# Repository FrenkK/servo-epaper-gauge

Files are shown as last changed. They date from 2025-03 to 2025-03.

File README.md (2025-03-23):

# Triple Analog Gauge Using Servos and an E-paper Display
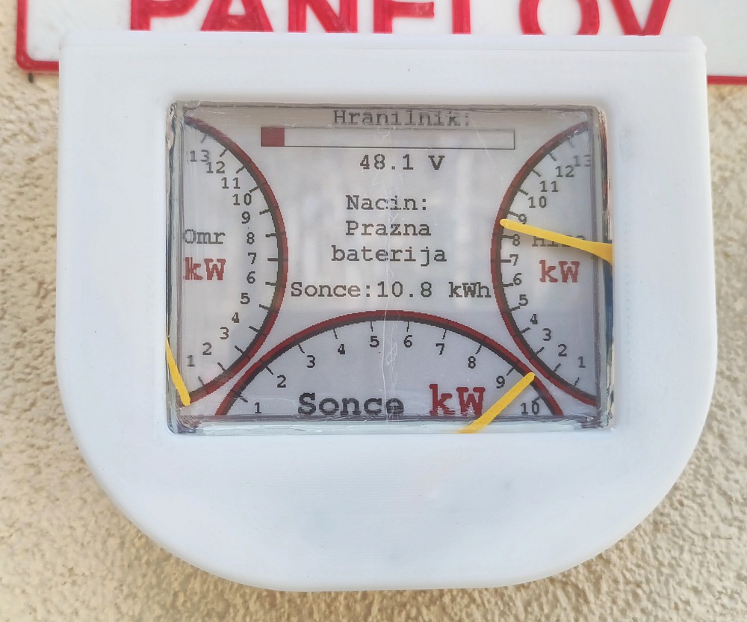
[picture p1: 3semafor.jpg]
The gauge

A simple triple gauge using three servos and a 3-color e-paper display used for indicating a solar system state.
The project uses 3 90g servos to move needles and an e-paper display to display both gauge markings and extra information about the system state.
Inspired by [Arne van Iterson](https://arnweb.nl/gitea/arne/EinkAnalog).

# What you need
- An ESPP32 dev board
- Waveshare 4.2" 3-color e-paper display (there are two versions, one with screw holes in the back and one with screw holes next to the display, you need the first one or the mounting biard will not fit)
- 3 90g servos
- Some screws from your screw drawer ;)
- A 3D-printer
- Weatherproof filament like ASA or ABS
- Some acryllic to make the window

# STEP files
The project includes STEP files for 3d-printing an enclosure:
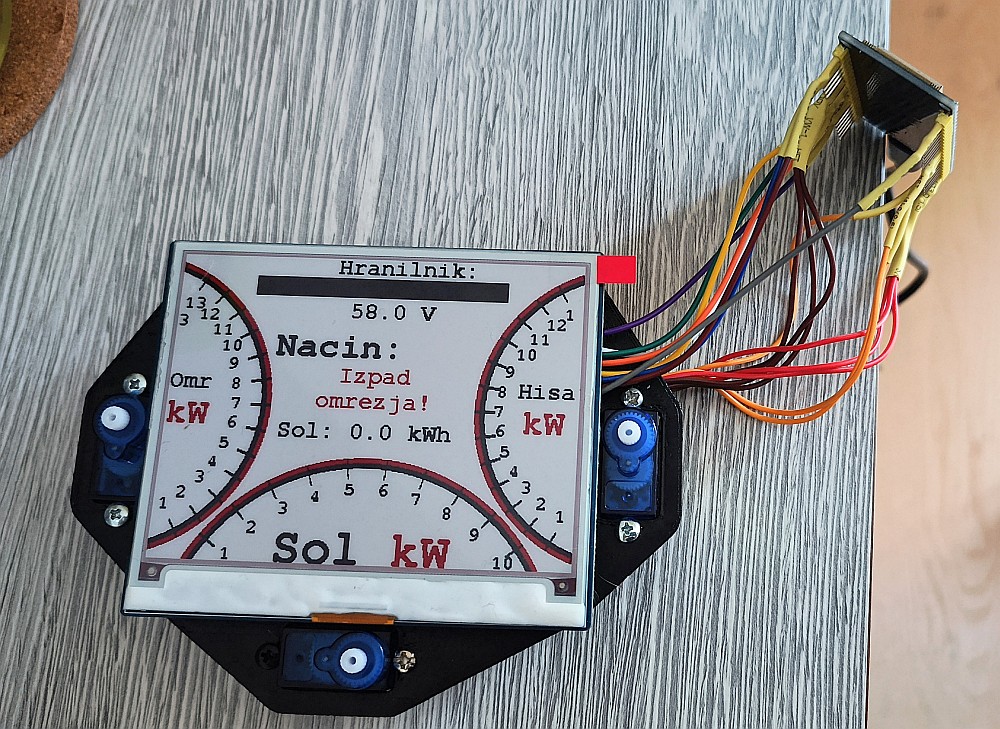
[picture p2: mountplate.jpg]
The mounting plate
- Ogrodje za tri.step is the mounting plate for the servos and the e-paper display (Waveshare 3-color 4.2") mounting plate. 
- Ohišje za semafor lope.step is the housing with a cover. Print this in something that will take direct sunlight, like ABS or ASA. You have to drill a hole for the power cable in an appropriate spot. If exposed to elements, glue an acryllic plate on the inside using silicone to make it watertight. Finally, slide the mounting plate in the grooves inside and use a drop of superglue to mount the cover.
- Kazalec za lopo.step contains two versions of needles for the servos, short one is for the two side servos and the long one for the center one.

# Arduino code
This is the code for the ESP32 controller driving the display and servos. The header files are for the GxEPD2 library and contain display definition and pin connections.

# Connections
- E-paper display should be connected to 3.3V and GND power rails of the ESP32 and the pins listed in the 'GxEPD2_wiring_examples.h' header file for the exact ESP32 board you are using.
- Connect the servos power lines to the 5V and GND power rails of the ESP32 board, and then connect the control lines to the pins set in the Arduino code (25, 26, and 27 in my case).
- Finally, connect the ESP32 board to an USB power cable or directly solder a 1A, 5V voltage supply to the 5V and GND power rails of the ESP32 board.

# TBD
- OTA firmware upload
- Better Wi-fi disturbances handling
- Less lame programming skills

Happy DIY :)
Franci

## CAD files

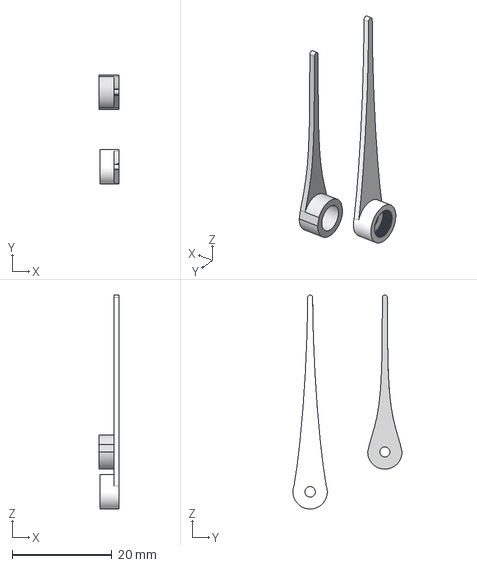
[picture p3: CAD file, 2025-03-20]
Kazalec za lopo.step
4.00 x 21.9 x 43.0 mm

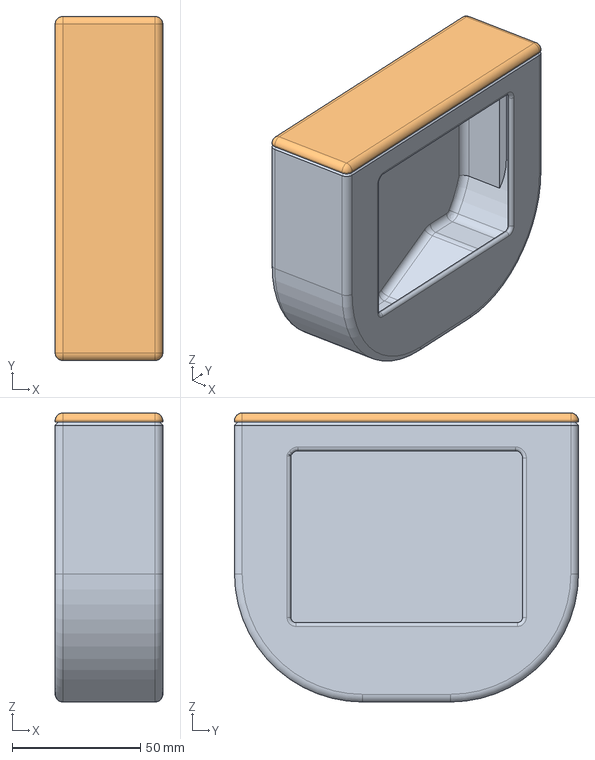
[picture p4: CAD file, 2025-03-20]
Ohišje za semafor lope.step
42.0 x 134.2 x 112.7 mm

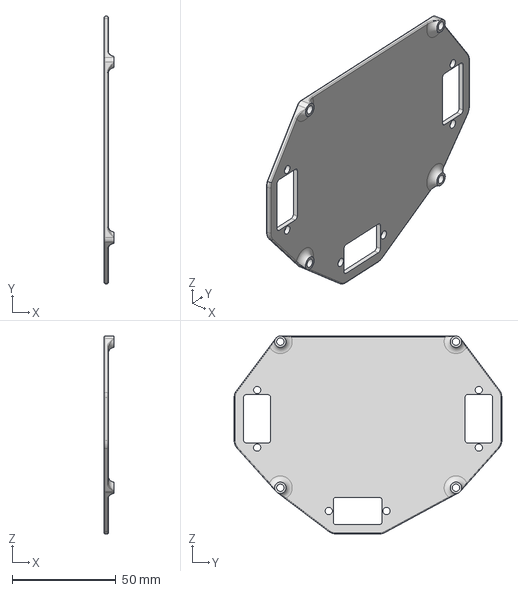
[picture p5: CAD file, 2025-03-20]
Ogrodje za tri.step
4.68 x 129.2 x 95.6 mm

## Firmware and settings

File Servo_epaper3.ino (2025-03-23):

#define ENABLE_GxEPD2_GFX 0

#include <GxEPD2_BW.h> // Include library for monochrome e-paper display
#include <GxEPD2_3C.h> // Include library for tri-color e-paper display
#include <Fonts/FreeMonoBold18pt7b.h> // Include font library for bold text at 18pt
#include <Fonts/FreeMonoBold9pt7b.h> // Include font library for bold text at 9pt
#include <Fonts/FreeMonoBold24pt7b.h> // Include font library for bold text at 24pt
#include <Fonts/FreeMonoBold12pt7b.h> // Include font library for bold text at 12pt
#include <Fonts/FreeMono12pt7b.h> // Include font library for standard text at 12pt
#include "GxEPD2_display_selection_new_style.h" // Include custom display selection header file
#include <ESP32Servo.h> // Include servo library for motor control
#include <WiFi.h> // Include WiFi library for network communication
#include "Adafruit_MQTT.h" // Include MQTT library for messaging
#include "Adafruit_MQTT_Client.h" // Include MQTT client library

// Define WiFi access parameters
// Code credit: https://randomnerdtutorials.com/esp32-useful-wi-fi-functions-arduino/#3
const char *SSID = "ssid"; // Network name (SSID)
const char *wifiPass = "pass"; // Password for network connection
const char *hostName = "prikaz-lopa"; // Hostname for MQTT communication
WiFiClient wifiClient; // Create WiFi client object

// Define MQTT broker parameters
// Code credit: https://www.donskytech.com/adafruit-mqtt-library-tutorial/
const char *mqttBroker = "broker"; // Name of MQTT broker
const int mqttPort = 1883; // Port number for MQTT communication
const char *mqttUserName = "user"; // Username for MQTT connection
const char *mqttUserPassword = "pass"; // Password for MQTT connection

// Create Adafruit MQTT client object with WiFi client as underlying transport layer
Adafruit_MQTT_Client mqtt(&wifiClient, mqttBroker, mqttPort, mqttUserName, mqttUserPassword);

// Define MQTT subscription topics
const char *subscribeGridTopic = "power/grid"; // Topic for grid power data
const char *subscribeSolarTopic = "power/solar"; // Topic for solar production power data
const char *subscribeHouseTopic = "power/house"; // Topic for house power consumption data
const char *subscribeModeTopic = "power/mode"; // Topic for mode of operation (normal or emergency)
const char *subscribeBatteryTopic = "power/battery"; // Topic for battery voltage and state
const char *subscribeEnergyTopic = "power/energy"; // Topic for total energy produced/consumed

// Create MQTT subscriber objects for each topic
Adafruit_MQTT_Subscribe gridPowerRef = Adafruit_MQTT_Subscribe(&mqtt, subscribeGridTopic, MQTT_QOS_0); // Subscribe to grid power data at QoS 1
Adafruit_MQTT_Subscribe solarPowerRef = Adafruit_MQTT_Subscribe(&mqtt, subscribeSolarTopic, MQTT_QOS_0); // Subscribe to solar panel power data at QoS 1
Adafruit_MQTT_Subscribe housePowerRef = Adafruit_MQTT_Subscribe(&mqtt, subscribeHouseTopic, MQTT_QOS_0); // Subscribe to house power consumption data at QoS 1
Adafruit_MQTT_Subscribe modeRef = Adafruit_MQTT_Subscribe(&mqtt, subscribeModeTopic, MQTT_QOS_0); // Subscribe to mode of operation (normal or emergency) at QoS 1
Adafruit_MQTT_Subscribe batteryRef = Adafruit_MQTT_Subscribe(&mqtt, subscribeBatteryTopic, MQTT_QOS_0); // Subscribe to battery voltage and state data at QoS 1
Adafruit_MQTT_Subscribe energyRef = Adafruit_MQTT_Subscribe(&mqtt, subscribeEnergyTopic, MQTT_QOS_0); // Subscribe to total energy produced/consumed data at QoS 1

//Servo defs
//Left servo init
Servo leftServo;  // create servo object to control a servo
int leftServoStart = 20; // servo value for 0
int leftServoEnd = 177; // servo value for maxPower
int leftServoPin = 25; // Pin number for connecting left servo
//Servo 2 init
Servo centerServo;  // create servo object to control a servo
int centerServoStart = 177; // servo value for 0
int centerServoEnd = 31; // servo value for maxPower
int centerServoPin = 26; // pin number for connecting center servo
//Servo 3 init
Servo rightServo;  // create servo object to control a servo
int rightServoStart = 177; // servo value for 0
int rightServoEnd = 20; // servo value for maxPower
int rightServoPin = 27; // pin number for connecting right servo

//Globals
String mode1 = ""; // First line of status display
String mode2 = ""; // Second line of status display
float batteryVoltage = 58; // Battery voltage
float producedEnergy = 0; // Total energy produced today
long lastRefresh = 0; // Timestamp of last screen refresh
bool normalMode = false; // Normal mode flag

//Constants

// Status strings
// The following constants are used to display the current mode on the screen.
// These string values represent different modes of operation and their corresponding status messages.

// In emergency charging mode (deep discharge prevention), show the following messages on the first and second lines.
const String emergencyString1 = "Zasilno";
const String emergencyString2 = "polnjenje";
// If the battery is empty, show these strings on the first and second lines.
const String batEmptyString1 = "Prazna";
const String batEmptyString2 = "baterija";
// When in normal mode, display these strings on the first and second lines.
const String normalString1 = "Na";
const String normalString2 = "bateriji";
// If the battery is full, display these strings on the first and second lines.
const String fullString1 = "Polna";
const String fullString2 = "baterija";
// When there's no grid power available, display these strings on the first and second lines.
const String noGridString1 = "Izpad";
const String noGridString2 = "omrezja!";

// Number constants
// Maximum house power consumption
const float maxHousePower = 14000; // Watts (W)
// Maximum grid power consumption
const float maxGridPower = 14000; // W
// Maximum solar panel power generation
const float maxSolarPower = 11000; // W
// Maximum battery voltage
const float maxVoltage = 58; // Volts (V)
// Minimum battery voltage
const float minVoltage = 47; // V
// Low battery threshold, used to change display color to red when lower than this value
const float lowVoltage = 49; // V
// Minimum and maximum angles for left servo motor in radians
const float alphaMinLeft = 20 * DEG_TO_RAD; // rad
const float alphaMaxLeft = 160 * DEG_TO_RAD; // rad
// Minimum and maximum angles for center servo motor in radians
const float alphaMinCenter = 25 * DEG_TO_RAD; // rad
const float alphaMaxCenter = 155 * DEG_TO_RAD; // rad
// Minimum and maximum angles for right servo motor in radians
const float alphaMinRight = 20 * DEG_TO_RAD; // rad
const float alphaMaxRight = 160 * DEG_TO_RAD; // rad
// Coordinates of center points for left, center, and right servos on the screen
const int xCLeft = -49; // x-coordinate (pixels)
const int yCLeft = 150; // y-coordinate (pixels)
const int RLeft = 150; // radius (pixels)
const int xCCenter = 200; // x-coordinate (pixels)
const int yCCenter = 389; // y-coordinate (pixels)
const int RCenter = 190; // radius (pixels)
const int xCRight = 449; // x-coordinate (pixels)
const int yCRight = 150; // y-coordinate (pixels)
const int RRight = 150; // radius (pixels)
// Refresh time for display in milliseconds
const long refreshTime = 600000; // ms

/**
 * Initialize WiFi connection.
 *
 * Connects to the specified network with the given credentials and sets up WiFi configuration.
 */
void initWiFi() {
  // Set host name of ESP32 device
  WiFi.setHostname(hostName);

  // Set WiFi mode to station (STA) mode, which means we're a client, not an access point
  WiFi.mode(WIFI_STA);

  // Start WiFi connection with given credentials
  WiFi.begin(SSID, wifiPass);

  // Print dots while waiting for WiFi connection
  Serial.print("Connecting to WiFi ..");
  while (WiFi.status() != WL_CONNECTED) {
    Serial.print('.');
    delay(1000); // wait 1 second between dots
  }

  // Print successful connection message and display local IP address
  Serial.println(WiFi.localIP());
}

// Function to connect and reconnect as necessary to the MQTT server.
// Should be called in the loop function and it will take care if connecting.
void connectToMQTTServer() {
  // Print a comment indicating that this function is being called
  Serial.println("Connecting to MQTT...");

  int8_t ret = mqtt.connect(); // Attempt connection to MQTT server

  while (ret != 0) { // Check if connection was successful
    // If connection failed, print an error message and wait for 10 seconds before retrying
    Serial.print("Failed to connect: ");
    Serial.println(mqtt.connectErrorString(ret));
    Serial.println("Retrying MQTT connection in 10 seconds...");
    delay(10000); // Wait for 10 seconds

    ret = mqtt.connect(); // Attempt connection again
  }

  // Print a comment indicating that the connection was successful
  Serial.println("MQTT Connected!");
}

// Function to draw the battery gauge on the e-paper display.
// The battery gauge is a rectangle with a filled part that represents the battery voltage.
// The filled part is colored black if the battery voltage is above the low voltage threshold, and red otherwise.
// The battery voltage is displayed in volts at the bottom of the gauge.
// The function takes the battery voltage as input and draws the gauge accordingly.
void drawBatteryGauge(float batteryVoltage)
{
  int gaugeWidth = 250; // Width of the battery gauge
  int gaugeHeight = 20; // Height of the battery gauge
  int gaugeX = 75; // X position of the battery gauge
  int gaugeY = 20; // Y position of the battery gauge

  // Draw the outline of the battery
  display.drawRect(gaugeX, gaugeY, gaugeWidth, gaugeHeight, GxEPD_BLACK);

  // Limit values for bar
  float tempBatteryVoltage=0;
  if ((batteryVoltage>minVoltage)&&(batteryVoltage<maxVoltage)) { // If battery voltage is within limits, use it
    tempBatteryVoltage=batteryVoltage;
  } else if (batteryVoltage<=minVoltage) { // If battery voltage is below minimum limit, use minimum
    tempBatteryVoltage=minVoltage;
  } else if (batteryVoltage>=maxVoltage) { // If battery voltage is above maximum limit, use maximum
    tempBatteryVoltage=maxVoltage;
  }

  // Calculate the width of the filled part based on battery voltage
  int filledWidth = ((tempBatteryVoltage-minVoltage)/(maxVoltage-minVoltage)) * gaugeWidth;

  // Draw text for battery
  display.setFont(&FreeMonoBold12pt7b);
  display.setTextColor(GxEPD_BLACK);
  display.setCursor(145, 15);
  display.print("Hranilnik:");

  // Draw the filled part of the battery
  // If battery voltage is above the low voltage threshold, fill the gauge with black, else red
  if (batteryVoltage > lowVoltage) {
    display.fillRect(gaugeX + 1, gaugeY + 1, filledWidth - 2, gaugeHeight - 2, GxEPD_BLACK);
  } else {
    display.fillRect(gaugeX + 1, gaugeY + 1, filledWidth - 2, gaugeHeight - 2, GxEPD_RED);
  }

  // Draw the battery voltage value in volts
  display.setTextColor(GxEPD_BLACK);
  display.setFont(&FreeMonoBold12pt7b);
  display.setCursor(170, 60);
  display.printf("%.1f V", batteryVoltage);
}

// Function to draw the graphics on the e-paper display.
// The function draws the battery gauge, charging mode information, and power gauges for grid, solar, and house.
// The function uses the GxEPD2 library using Adafruit GFX graphics library for drawing shapes and text on the display.
// The function takes no input and returns nothing.
void drawGraphics()
{
  //Initialize the e-paper interface
  display.init(0, true, 2, true); // Initialize the display with full refresh, no partial refresh supported on 3-color displays
  display.setRotation(0); // Landscape orientation
  display.setTextWrap(false); // Disable text wrapping
  
  display.firstPage(); // Start drawing
  do {
    // Clear the screen
    display.fillScreen(GxEPD_WHITE);

    // Draw the battery gauge
    drawBatteryGauge(batteryVoltage);
    
    //Draw charging mode info
    //Draw title for charging mode
    display.setTextColor(GxEPD_BLACK);
    display.setFont(&FreeMonoBold12pt7b);
    display.setCursor(200-(6*14/2), 100);
    display.println("Nacin:");
    //Red color when abnormal mode or off, black otherwise
    if (!normalMode) {
      display.setTextColor(GxEPD_RED);
    }
    //Draw mode strings
    display.setFont(&FreeMonoBold12pt7b);
    display.setCursor(200-(mode1.length()*14/2), 125);
    display.print(mode1);
    display.setCursor(200-(mode2.length()*14/2), 150);
    display.print(mode2);

    //Draw total produced energy today
    display.setTextColor(GxEPD_BLACK);
    display.setFont(&FreeMonoBold12pt7b);
    display.setCursor(103, 185);
    display.printf("Sonce:%.1f kWh", producedEnergy);

    //Draw the left analog gauge
    display.fillCircle(xCLeft, yCLeft, RLeft, GxEPD_RED); //Draw the red circle of the gauge
    display.fillCircle(xCLeft, yCLeft, RLeft-5, GxEPD_BLACK); //Draw the black line inside the red circle
    display.fillCircle(xCLeft, yCLeft, RLeft-10, GxEPD_WHITE); // Delete everything under the black line by drawing a white circle

    //Draw gauge lines per kilowatt (triple lines for added thickness)
    for (int i=0;i<=round(maxGridPower/1000);i++) { // for each kilowatt of the gauge range
      int x = xCLeft + (int) (RLeft*sin(((alphaMaxLeft-alphaMinLeft)/round(maxGridPower/1000)*i)+alphaMinLeft)); // calculate x position of the line
      int y = yCLeft + (int) (RLeft*cos(((alphaMaxLeft-alphaMinLeft)/round(maxGridPower/1000)*i)+alphaMinLeft)); // calculate y position of the line
      display.drawLine(xCLeft, yCLeft, x, y-1, GxEPD_BLACK); // draw first line
      display.drawLine(xCLeft, yCLeft, x, y, GxEPD_BLACK); // draw second line
      display.drawLine(xCLeft, yCLeft, x, y+1, GxEPD_BLACK); // draw third line
    }
    
    display.fillCircle(xCLeft, yCLeft, RLeft-20, GxEPD_WHITE); // Delete everything under the gauge and the lines again
    
    //Draw black numbers on the gauge
    display.setTextColor(GxEPD_BLACK);
    display.setFont(&FreeMonoBold9pt7b);
    for (int i=1;i<round(maxGridPower/1000);i++) { // one number per kilowatt, omit zero and last number
      display.setCursor(xCLeft - 4 + (int) ((float)(RLeft-35)*sin((((alphaMaxLeft-alphaMinLeft)/round(maxGridPower/1000))*i)+alphaMinLeft)), yCLeft + 4 + (int) ((float)(RLeft-35)*cos((((alphaMaxLeft-alphaMinLeft)/round(maxGridPower/1000))*i)+alphaMinLeft))); // calculate position of the number
      display.print(i); // print the number
    }
    
    //Draw gauge legend
    display.setFont(&FreeMonoBold12pt7b);
    display.setCursor(0, 135);
    display.print("Omr");
    //Draw red kW
    display.setCursor(0, 170);
    display.setTextColor(GxEPD_RED);
    display.setFont(&FreeMonoBold18pt7b);
    display.print("kW");

    //Draw the center analog gauge, see comments for left gauge for explanation
    display.fillCircle(xCCenter, yCCenter, RCenter, GxEPD_RED);
    display.fillCircle(xCCenter, yCCenter, RCenter-5, GxEPD_BLACK);
    display.fillCircle(xCCenter, yCCenter, RCenter-10, GxEPD_WHITE);

    //Draw gauge lines per kilowatt (three for added thickness)
    for (int i=0;i<=round(maxSolarPower/1000);i++) {
      int x = xCCenter - (int) (RCenter*cos(((alphaMaxCenter-alphaMinCenter)/round(maxSolarPower/1000)*i)+alphaMinCenter));
      int y = yCCenter - (int) (RCenter*sin(((alphaMaxCenter-alphaMinCenter)/round(maxSolarPower/1000)*i)+alphaMinCenter));
      display.drawLine(xCCenter, yCCenter, x, y-1, GxEPD_BLACK);
      display.drawLine(xCCenter, yCCenter, x, y, GxEPD_BLACK);
      display.drawLine(xCCenter, yCCenter, x, y+1, GxEPD_BLACK);
    }
    //Delete area under gauge
    display.fillCircle(xCCenter, yCCenter, RCenter-20, GxEPD_WHITE);
    
    //Draw numbers
    display.setTextColor(GxEPD_BLACK);
    display.setFont(&FreeMonoBold9pt7b);
    for (int i=1;i<round(maxSolarPower/1000);i++) {
      display.setCursor(xCCenter - 4 - (int) ((float)(RCenter-30)*cos((((alphaMaxCenter-alphaMinCenter)/round(maxSolarPower/1000))*i)+alphaMinCenter)), yCCenter + 4 - (int) ((float)(RCenter-30)*sin((((alphaMaxCenter-alphaMinCenter)/round(maxSolarPower/1000))*i)+alphaMinCenter)));
      display.print(i);
    }
    
    //Draw gauge legend
    display.setFont(&FreeMonoBold18pt7b);
    display.setCursor(110, 299);
    display.print("Sonce ");
    //Draw red kW
    display.setTextColor(GxEPD_RED);
    display.setFont(&FreeMonoBold24pt7b);
    display.print("kW");

    //Draw the right analog gauge, see comments for left gauge for explanation
    display.fillCircle(xCRight, yCRight, RRight, GxEPD_RED);
    display.fillCircle(xCRight, yCRight, RRight-5, GxEPD_BLACK);
    display.fillCircle(xCRight, yCRight, RRight-10, GxEPD_WHITE);

    //Draw gauge lines per kilowatt (three for added thickness)
    for (int i=0;i<=round(maxHousePower/1000);i++) {
      int x = xCRight - (int) (RRight*sin(((alphaMaxRight-alphaMinRight)/round(maxHousePower/1000)*i)+alphaMinRight));
      int y = yCRight + (int) (RRight*cos(((alphaMaxRight-alphaMinRight)/round(maxHousePower/1000)*i)+alphaMinRight));
      display.drawLine(xCRight, yCRight, x, y-1, GxEPD_BLACK);
      display.drawLine(xCRight, yCRight, x, y, GxEPD_BLACK);
      display.drawLine(xCRight, yCRight, x, y+1, GxEPD_BLACK);
    }
    //Delete area under gauge
    display.fillCircle(xCRight, yCRight, RRight-20, GxEPD_WHITE);
    
    //Draw numbers
    display.setTextColor(GxEPD_BLACK);
    display.setFont(&FreeMonoBold9pt7b);
    for (int i=1;i<round(maxHousePower/1000);i++) {
      display.setCursor(xCRight - 5 - (int) ((float)(RRight-23)*sin((((alphaMaxRight-alphaMinRight)/round(maxHousePower/1000))*i)+alphaMinRight)), yCRight + 4 + (int) ((float)(RRight-35)*cos((((alphaMaxRight-alphaMinRight)/round(maxHousePower/1000))*i)+alphaMinRight)));
      display.print(i);
    }
    
    //Draw gauge legend
    display.setFont(&FreeMonoBold12pt7b);
    display.setCursor(340, 135);
    display.print("Hisa");
    //Draw red kW
    display.setCursor(345, 170);
    display.setTextColor(GxEPD_RED);
    display.setFont(&FreeMonoBold18pt7b);
    display.print("kW");
  }
  while (display.nextPage()); // Draw the buffer to display
  
  lastRefresh = millis(); // Update the timestamp of the last screen refresh
  display.powerOff(); // Turn off the display to save power and prevent artefacts
  display.end();  // End the display use
}

// Function for moving the grid power needle on the gauge.
// The function takes a message string from the MQTT subscription and its length as input and moves the needle accordingly.
// The function also checks for limits and refreshes the display as needed.
void gridPowerNeedle(char *message, uint16_t len)
{
  int powerW = atof(message); // Convert the message string to a floating-point number (kilowatts)
  if (powerW>maxGridPower) { // If power is above the maximum limit, set it to the maximum
    powerW=maxGridPower;
  } else if (powerW<0) { // If power is below the minimum limit, set it to zero
    powerW=0;
  }
  
  //Debug messages
  /*Serial.print("Received grid power message: ");
  Serial.println(message);*/
  
  // Move the left servo motor needle based on the power value received from the MQTT subscription
  leftServo.write(leftServoStart - (((float)powerW/maxGridPower) * (leftServoStart-leftServoEnd))); // Move the needle to the corresponding angle
  
  //Debug messages
  /*Serial.print("Servo set to: ");
  Serial.println(leftServo.read());*/
  
  if ((lastRefresh + refreshTime)<millis()) { // If it's time to refresh the screen, refresh it
    drawGraphics();
  }
}

// Function for moving the solar power needle on the gauge.
// See comments for gridPowerNeedle for explanation. No display refresh is needed here.
void solarPowerNeedle(char *message, uint16_t len)
{
  int powerW = atof(message);
  if (powerW>maxSolarPower) {
    powerW=maxSolarPower;
  } else if (powerW<0) {
    powerW=0;
  }
 
  /*Serial.print("Received solar power message: ");
  Serial.println(message);*/
  centerServo.write(centerServoStart - (((float)powerW/maxSolarPower) * (centerServoStart-centerServoEnd)));
  /*Serial.print("Servo set to: ");
  Serial.println(centerServo.read());*/
}

// Function for moving the house power needle on the gauge.
// See comments for solarPowerNeedle for explanation.
void housePowerNeedle(char *message, uint16_t len)
{
  int powerW = atof(message);
  if (powerW>maxHousePower) {
    powerW=maxHousePower;
  } else if (powerW<0) {
    powerW=0;
  }
  /*Serial.print("Received house power message: ");
  Serial.println(message);*/
  rightServo.write(rightServoStart - (((float)powerW/maxHousePower) * (rightServoStart-rightServoEnd)));
  /*Serial.print("Servo set to: ");
  Serial.println(rightServo.read());*/
}
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
void loop()
{
  // Connect to MQTT
  connectToMQTTServer();

  // this is our 'wait for incoming subscription packets and callback em' busy subloop
  // try to spend your time here:
  mqtt.processPackets(10000);

  mqtt.ping(); // keep the mqtt connection alive

  if (WiFi.status() != WL_CONNECTED) { // If WiFi connection is lost, restart the ESP32
    ESP.restart();
  }
}

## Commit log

2025-03-20 Added ESP32 arduino code
2025-03-20 Added step files
    [Kazalec za lopo.step, Ogrodje za tri.step, Ohišje za semafor lope.step]
